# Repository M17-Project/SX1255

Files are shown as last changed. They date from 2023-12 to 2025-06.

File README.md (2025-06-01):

[][cc-by-nc-sa]

# SX1255
Minimalistic evaluation board for the SX1255 RF transceiver chip, with PMOD connectors.

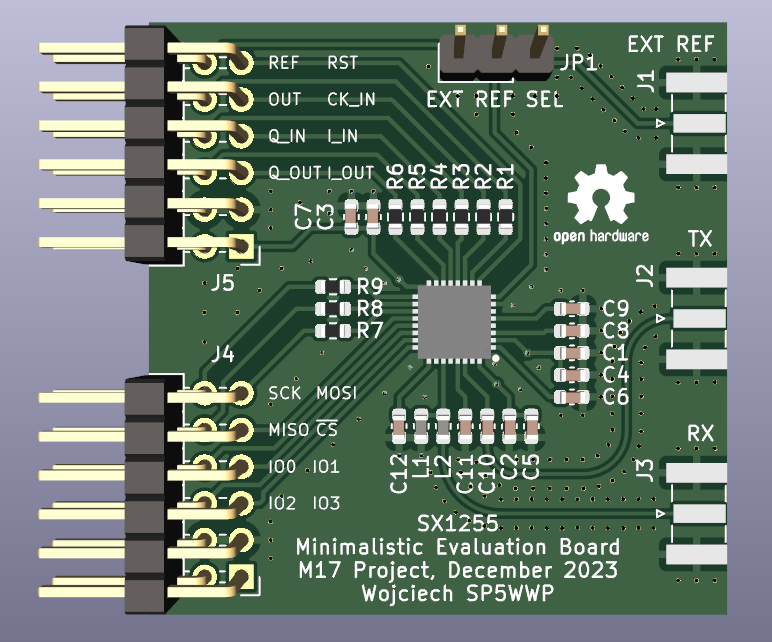
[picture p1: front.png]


## Clocking
Remember to provide a clock signal at the PMOD *REF* pin or *EXT_REF* SMA connector. The source is selectable with a jumper.
A range of clock frequencies can be used, see the SX1255's documentation for details.

## Raspberry Pi GPIO header connections
| PMOD pin name | RPi header pin number |
|---|---|
| **VCC** | **1** (*3.3V*) |
| **OUT** | **12** (*GPIO18*) |
| **MOSI** | **19** (*SPI_MOSI*) |
| **MISO** | **21** (*SPI_MISO*) |
| **RST** | **22** (*GPIO25*) |
| **SCK** | **23** (*SPI_CLK*) |
| **/CS** | **24** (*SPI_CE0_N*)  |
| **IO2** | **35** (*GPIO19*) |
| **I_OUT** | **38** (*GPIO20*) |
| **GND** | **39** (*GND*) |
| **I_IN** | **40** (*GPIO21*) |

Sample Raspberry Pi code for SX1255 control can be found [here](https://gist.github.com/sp5wwp/25fa989ebd98b3b707eadae9b63af679).
[I2S slave overlay](https://github.com/AkiyukiOkayasu/RaspberryPi_I2S_Slave) is required.

## License
This work is licensed under a
[Creative Commons Attribution-NonCommercial-ShareAlike 4.0 International License][cc-by-nc-sa].

[][cc-by-nc-sa]

[cc-by-nc-sa]: http://creativecommons.org/licenses/by-nc-sa/4.0/
[cc-by-nc-sa-image]: https://licensebuttons.net/l/by-nc-sa/4.0/88x31.png
[cc-by-nc-sa-shield]: https://img.shields.io/badge/License-CC%20BY--NC--SA%204.0-lightgrey.svg

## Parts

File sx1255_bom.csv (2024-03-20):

Reference | Value | Footprint | Datasheet | Height | LCSC Part# | MPN | PN | Qty
C1-C3 | 10n | Capacitor_SMD:C_0603_1608Metric | ~ |  | C100042 | C0603C103K5RAC7081 | C0603C103K5RAC7081 | 3
C4-C9, C12 | 100n | Capacitor_SMD:C_0603_1608Metric | ~ |  | C14663 | C0603C104M5RAC7411 | C0603C104M5RAC7411 | 7
C10 | 33p | Capacitor_SMD:C_0603_1608Metric | ~ |  | C107047 |  |  | 1
C11 | 27p | Capacitor_SMD:C_0603_1608Metric | ~ |  | C107045 |  |  | 1
IC1 | SX1255 | QFN50P500X500X80-33N-D | https://datasheet.datasheetarchive.com/originals/distributors/DKDS-5/90665.pdf | 0.8 | C89372 | 947-SX1255IWLTRT | 947-SX1255IWLTRT | 1
J1 | EXT_CLK_IN | Connector_Coaxial:SMA_Samtec_SMA-J-P-X-ST-EM1_EdgeMount | ~ |  | C496550 | - | - | 1
J2 | TX_SMA | Connector_Coaxial:SMA_Samtec_SMA-J-P-X-ST-EM1_EdgeMount | ~ |  | C496550 | - | - | 1
J3 | RX_SMA | Connector_Coaxial:SMA_Samtec_SMA-J-P-X-ST-EM1_EdgeMount | ~ |  | C496550 | - | - | 1
J4, J5 | PMOD | Connector_PinHeader_2.54mm:PinHeader_2x06_P2.54mm_Horizontal | ~ |  | C706887 |  |  | 2
JP1 | EXT_CLK_SRC | Connector_PinHeader_2.54mm:PinHeader_1x03_P2.54mm_Vertical | ~ |  | C6332196 |  |  | 1
L1 | 82n | Inductor_SMD:L_0603_1608Metric | ~ |  | C346329 |  |  | 1
L2 | 39n | Inductor_SMD:L_0603_1608Metric | ~ |  | C74308 |  |  | 1
R1-R9 | 100R | Resistor_SMD:R_0603_1608Metric | ~ |  | C125923 | CRCW0603100RFKECC | CRCW0603100RFKECC | 9

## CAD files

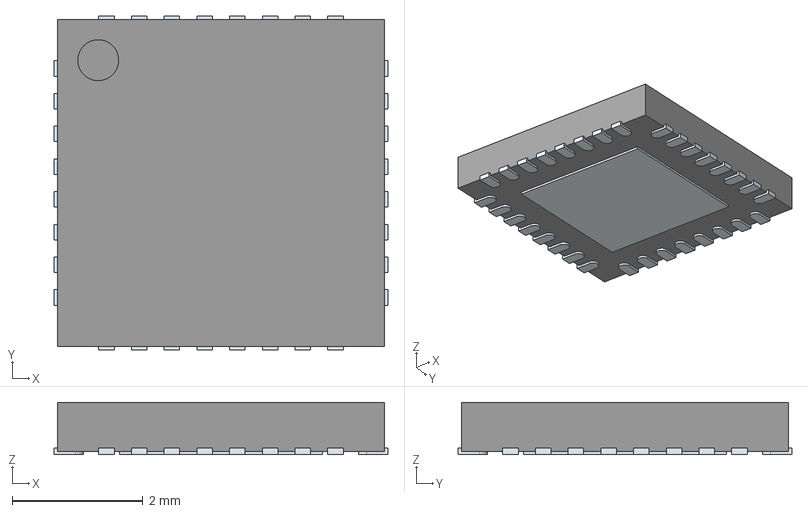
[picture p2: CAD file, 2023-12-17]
parts/SX1255IWLTRT.stp
5.10 x 5.10 x 0.8 mm
ThermalPin
PinsArrayLR
PinsArrayTB

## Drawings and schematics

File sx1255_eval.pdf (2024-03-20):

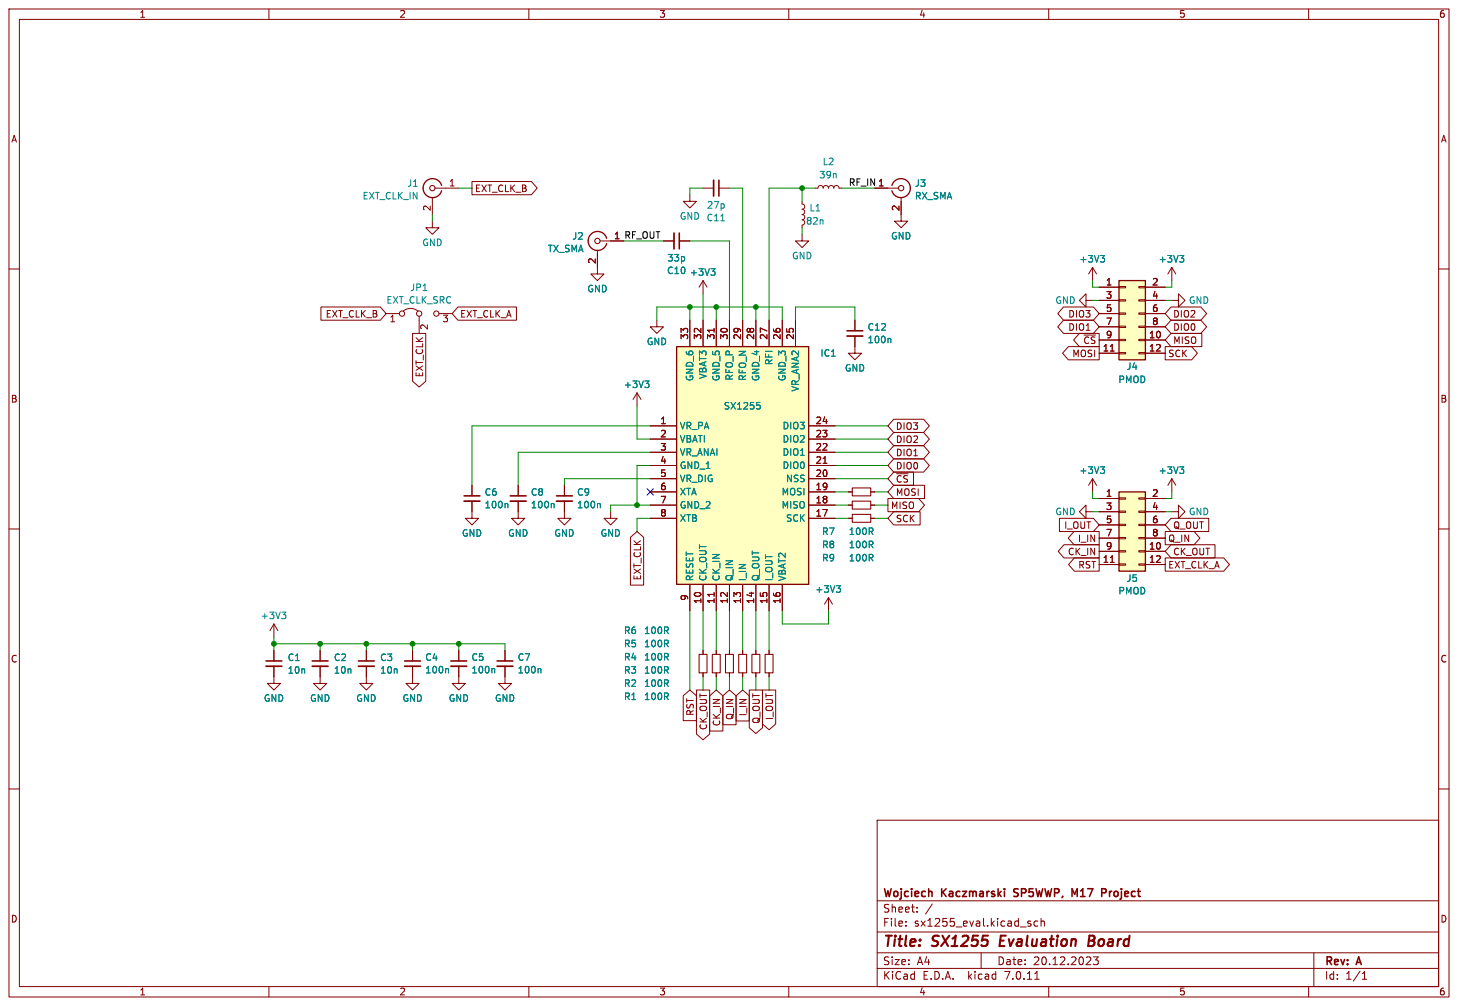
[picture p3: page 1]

~{CS} SCK MOSI MISO

Id: 1/1 Title: SX1255 Evaluation Board

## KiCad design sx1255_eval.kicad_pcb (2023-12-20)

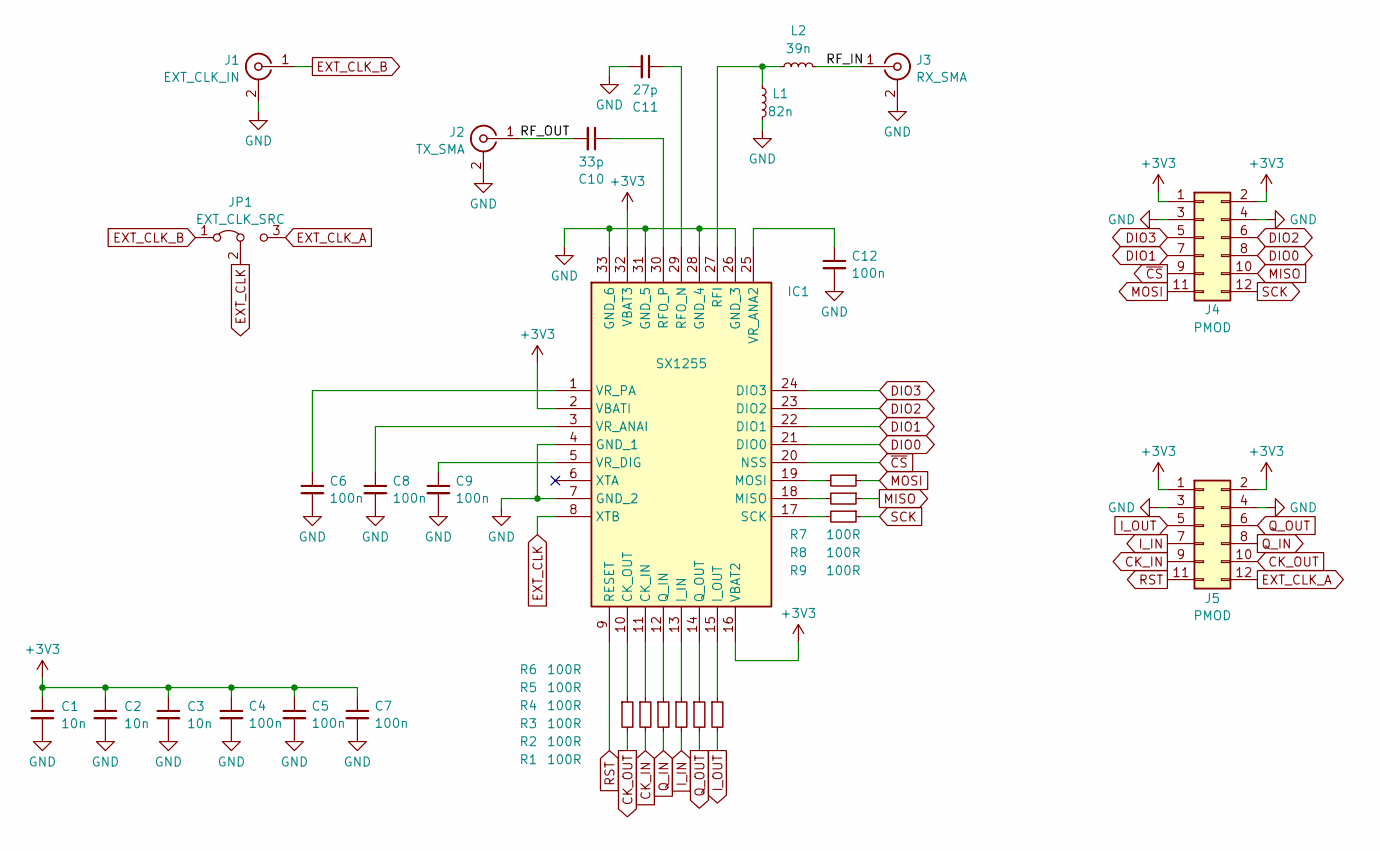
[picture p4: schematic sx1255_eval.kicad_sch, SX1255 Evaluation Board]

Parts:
C1, C2, C3: 10n; C_0603_1608Metric; MPN C0603C103K5RAC7081; LCSC Part# C100042
C4, C5, C6, C7, C8, C9, C12: 100n; C_0603_1608Metric; MPN C0603C104M5RAC7411; LCSC Part# C14663
C10: 33p; C_0603_1608Metric; LCSC Part# C107047
C11: 27p; C_0603_1608Metric; LCSC Part# C107045
IC1: SX1255; QFN50P500X500X80-33N-D; MPN 947-SX1255IWLTRT; LCSC Part# C89372
J1: EXT_CLK_IN; SMA_Samtec_SMA-J-P-X-ST-EM1_EdgeMount; LCSC Part# C2913580
J2: TX_SMA; SMA_Samtec_SMA-J-P-X-ST-EM1_EdgeMount; LCSC Part# C2913580
J3: RX_SMA; SMA_Samtec_SMA-J-P-X-ST-EM1_EdgeMount; LCSC Part# C2913580
J4, J5: PMOD; PinHeader_2x06_P2.54mm_Horizontal; LCSC Part# C706886
JP1: EXT_CLK_SRC; PinHeader_1x03_P2.54mm_Vertical; LCSC Part# C6332196
L1: 82n; L_0603_1608Metric; LCSC Part# C346329
L2: 39n; L_0603_1608Metric; LCSC Part# C74308
R1, R2, R3, R4, R5, R6, R7, R8, R9: 100R; R_0603_1608Metric; MPN CRCW0603100RFKECC; LCSC Part# C125923

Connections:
+3V3: C1.1, C2.1, C3.1, C4.1, C5.1, C7.1, IC1.2 (VBATI), IC1.16 (VBAT2), IC1.32 (VBAT3), J4.1, J4.2, J5.1, J5.2
/RF_IN: J3.1 (In), L2.1
/RF_OUT: C10.2, J2.1 (In)
CK_IN: J5.9, R2.2
CK_OUT: J5.10, R1.2
DIO0: IC1.21 (DIO0), J4.8
DIO1: IC1.22 (DIO1), J4.7
DIO2: IC1.23 (DIO2), J4.6
DIO3: IC1.24 (DIO3), J4.5
EXT_CLK: IC1.8 (XTB), JP1.2 (C)
EXT_CLK_A: J5.12, JP1.3 (B)
EXT_CLK_B: J1.1 (In), JP1.1 (A)
GND: C1.2, C2.2, C3.2, C4.2, C5.2, C6.2, C7.2, C8.2, C9.2, C11.2, C12.2, IC1.4 (GND_1), IC1.7 (GND_2), IC1.26 (GND_3), IC1.28 (GND_4), IC1.31 (GND_5), IC1.33 (GND_6), J1.2 (Ext), J2.2 (Ext), J3.2 (Ext), J4.3, J4.4, J5.3, J5.4, L1.1
I_IN: J5.7, R4.2
I_OUT: J5.5, R6.2
MISO: J4.10, R8.1
MOSI: J4.11, R7.1
unnamed: IC1.11 (CK_IN), R2.1
unnamed: IC1.10 (CK_OUT), R1.1
unnamed: IC1.13 (I_IN), R4.1
unnamed: IC1.15 (I_OUT), R6.1
unnamed: IC1.18 (MISO), R8.2
unnamed: IC1.19 (MOSI), R7.2
unnamed: IC1.12 (Q_IN), R3.1
unnamed: IC1.14 (Q_OUT), R5.1
unnamed: IC1.27 (RFI), L1.2, L2.2
unnamed: C11.1, IC1.29 (RFO_N)
unnamed: C10.1, IC1.30 (RFO_P)
unnamed: IC1.17 (SCK), R9.2
unnamed: C12.1, IC1.25 (VR_ANA2)
unnamed: C8.1, IC1.3 (VR_ANAI)
unnamed: C9.1, IC1.5 (VR_DIG)
unnamed: C6.1, IC1.1 (VR_PA)
Q_IN: J5.8, R3.2
Q_OUT: J5.6, R5.2
RST: IC1.9 (RESET), J5.11
SCK: J4.12, R9.1
~CS: IC1.20 (NSS), J4.9

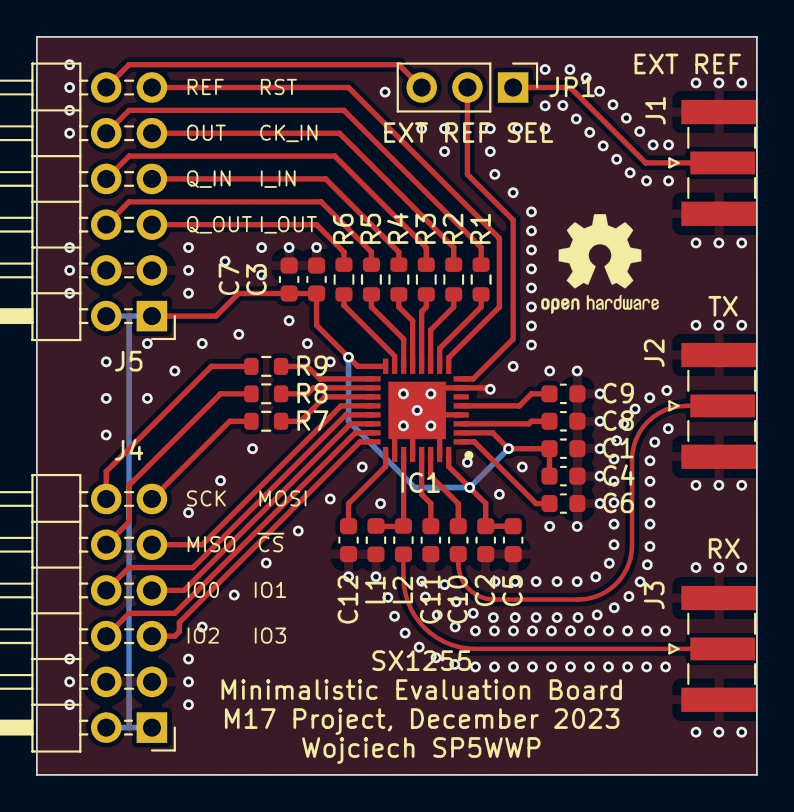
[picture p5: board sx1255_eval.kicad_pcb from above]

Board: 2 copper layers, 40.0 x 41.0 mm, 30 parts (0 on the bottom side), 38 nets.

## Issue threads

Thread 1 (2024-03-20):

SMA connectors are not available at JLCPCB

sp5wwp, 2024-03-20:
Female SMA connector `C2913580` is not available at JLCPCB. Find a replacement.

kc1awv, 2024-03-20:
LCSC C496550 looks like a good replacement. Lots in stock, too.

sp5wwp, 2024-03-20:
Fixed with e76ed05

Closed 2024-03-20.

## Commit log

2023-12-18 WIP PCB layout
    [sx1255_eval.kicad_pcb, sx1255_eval.kicad_sch]
2023-12-18 WIP PCB
    [sx1255_eval.kicad_pcb, sx1255_eval.kicad_sch]
2023-12-19 PCB cleanup
    [sx1255_eval.kicad_pcb]
2023-12-20 changed PCB orientation
    [sx1255_eval.kicad_pcb]
2023-12-20 PN update, gerbers
    minor silkscreen tweaks
    [sx1255_eval-B_Cu.gbl, sx1255_eval-B_Mask.gbs, sx1255_eval-B_Paste.gbp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]
2024-02-24 BOM update
    J4, J5 had wrong PN assigned (2x05 instead of 2x06 headers)
    [sx1255_bom.csv, sx1255_eval.kicad_sch]
2024-03-20 updated SMA conn PN
    removed fab files
    [sx1255_bom.csv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]

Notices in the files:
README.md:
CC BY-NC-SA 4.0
